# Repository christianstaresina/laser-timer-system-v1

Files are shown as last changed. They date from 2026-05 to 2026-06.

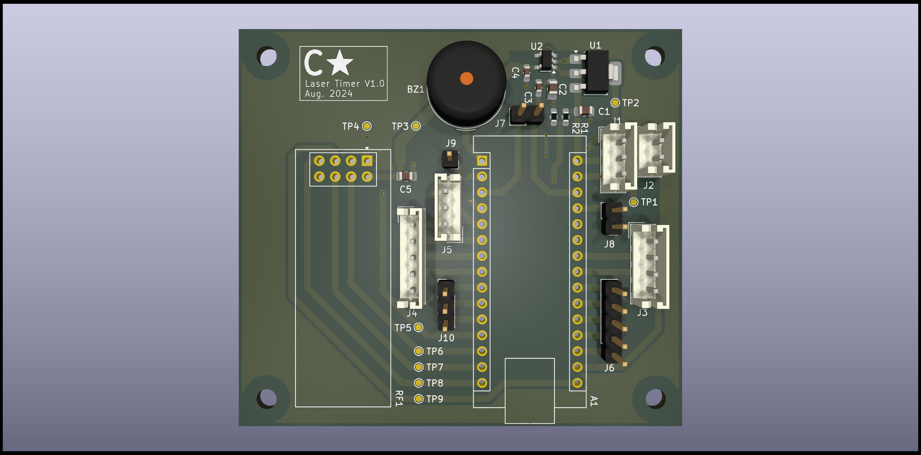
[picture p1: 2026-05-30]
docs/Laser_Timer_PCBA.jpg

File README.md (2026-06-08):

# Laser Timer System V1

A portable laser timer system consisting of a start gate and an end gate. When
the athlete crosses the start gate, the timer begins counting. When the athlete
crosses the end gate, the receiver stops the timer and shows the elapsed time on
its built-in LCD.

One common use is sprint timing: place the gates a measured distance apart,
start a run by crossing gate 1, then read the finish time and optional average
speed at gate 2.

## Repository layout

- `firmware/transmitter/laser_timer_v2_tx/` - Arduino sketch for the gate 1
  transmitter unit.
- `firmware/receiver/laser_timer_v2_rx/` - Arduino sketch for the gate 2
  receiver unit with LCD menu, stopwatch, speed settings, radio status, and
  buzzer settings.
- `firmware/common/radio_protocol_v2.h` - reference copy of the shared nRF24
  packet format. Each sketch also carries a local copy under `src/`; keep these
  protocol headers synchronized when changing radio commands or timing.
- `hardware/transmitter-or-receiver/` - KiCad source for the shared PCB.
- `production/transmitter-or-receiver/` - generated fabrication outputs,
  including Gerbers and BOM.

## Firmware v2 architecture

Firmware v2 uses two ATmega328-based units with nRF24L01+PA+LNA radios and
16x2 I2C LCDs:

1. The transmitter watches gate 1. When the gate 1 beam is broken, it sends a
   `CMD_GATE1_OPEN` burst to the receiver, shows "Timer counting", and waits for
   a finish message.
2. The receiver watches gate 2. When stopwatch mode is enabled and a gate 1
   open packet arrives, it starts timing. When the gate 2 beam is broken, it
   stops timing, displays the result, optionally displays speed, and sends
   `CMD_GATE2_CLOSED` back to the transmitter.
3. Both units use periodic or repeated packets for resilience: the transmitter
   sends heartbeat pings while idle and repeats gate-open packets while a run is
   active.

The shared radio protocol is defined by `radio_protocol_v2.h`:

- Packet shape: two packed bytes, `magic` (`0xA5`) and `cmd`.
- Commands: `CMD_GATE1_OPEN`, `CMD_GATE1_CLOSED`, `CMD_GATE2_CLOSED`, and
  `CMD_PING`.
- Radio settings: channel `108`, 250 Kbps data rate, 16-bit CRC, auto-ack
  enabled, and high PA level after startup settling.
- Pipe layout: address `"00002"` is transmitter-to-receiver, and `"00001"` is
  receiver-to-transmitter.

## Arduino setup

Open each sketch folder directly in the Arduino IDE:

- Transmitter: `firmware/transmitter/laser_timer_v2_tx`
- Receiver: `firmware/receiver/laser_timer_v2_rx`

Install the Arduino libraries used by the sketches:

- `RF24`
- `LiquidCrystal_I2C`
- Built-in Arduino libraries: `SPI`, `Wire`, and `EEPROM` (receiver settings)

The sketches are written for ATmega328-style boards. Source-verified pin usage:

| Function | Pin |
| --- | --- |
| Gate sensor input | `2` |
| Buzzer output | `1` |
| Encoder button | `3` |
| Encoder CLK | `4` |
| Encoder DAT | `5` |
| nRF24 CE | `9` |
| nRF24 CSN | `10` |
| SD card CS placeholder on receiver | `8` |
| Radio power enable | `A0` set `HIGH` at startup |
| LCD | I2C address `0x27`, 16 columns x 2 rows |

Both gate sensors are treated as active-high: `HIGH` means the laser beam is
broken.

## Operating workflow

1. Power the receiver and transmitter. Both show a pairing screen during radio
   startup. The transmitter blocks until it can send an acknowledged ping; the
   receiver shows "Link OK!" after the first valid packet.
2. Align both lasers. If a receiver beam is already broken while idle, the LCD
   shows "Align laser". The transmitter similarly shows "Gate 1 crossed" /
   "Align laser" if gate 1 starts open.
3. On the receiver, long-press the encoder button to open the menu, choose
   `Stopwatch`, then press the encoder. This enables the receiver to start a
   timed run from gate 1 packets.
4. Cross gate 1. The transmitter sends the start burst, beeps, and shows
   "Timer counting" / "Waiting gate 2". The receiver starts the stopwatch.
5. Cross gate 2. The receiver stops the timer, displays the finish time,
   optionally appends speed, sends the finish packet, and beeps if finish buzzer
   is enabled. The transmitter shows "Timer complete!" briefly before returning
   to its ready screen.

## Receiver menu and persisted settings

The receiver menu is controlled by the rotary encoder:

- Long press from the idle screen: open the main menu.
- Rotate: move through menu items.
- Short press: select the current item.
- Long press inside a menu: exit back to idle.

Main menu items:

- `Stopwatch` - enables timing. Gate 1 packets are ignored until this is
  selected.
- `Speed` - toggles speed display, selects preset distances (`40`, `10`, `5`,
  `2`, or `1` yard), edits a custom distance from `1` to `99` yards, and toggles
  display units between yards/MPH and meters/KPH. Distances are stored
  internally in yards; meter displays are converted from yards.
- `Radio` - shows link status or enters a re-pairing screen.
- `Buzzer` - toggles alignment and finish beeps independently.
- `Back` - returns to the idle display.

Receiver settings are stored in EEPROM at address `0` with magic byte `0x52`.
Defaults are speed enabled, 40-yard distance, 40-yard custom distance, align
buzzer enabled, finish buzzer enabled, and yard/MPH display units.

## Troubleshooting

- `Radio not found`: `radio.begin()` failed. Check nRF24 wiring, CE/CSN pins,
  SPI wiring, radio power, and the A0-controlled radio power rail.
- Pairing never completes: make sure both sketches use matching
  `radio_protocol_v2.h` values for channel, addresses, packet magic, and command
  IDs. The transmitter stays on the pairing screen until it receives an
  acknowledgement from the receiver.
- Receiver says `No TX signal`: the receiver has not seen a valid transmitter
  packet within the link timeout. Check transmitter power, radio range, antenna
  orientation, and matching protocol headers.
- Gate crossing does not start a run: enable `Stopwatch` from the receiver menu
  first. The receiver intentionally ignores gate 1 start packets while stopwatch
  mode is disabled.
- LCD says `Align laser`: the corresponding gate input is `HIGH`, which the
  firmware interprets as a broken beam. Re-align the laser/sensor pair or check
  sensor polarity.
- Speed looks wrong: verify the selected distance and units in the receiver
  `Speed` menu. KPH values are computed by converting the stored yard distance
  to meters.

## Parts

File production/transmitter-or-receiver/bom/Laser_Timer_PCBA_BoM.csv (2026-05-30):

# | Qty | DNP | Reference | Description | Value | Datasheet | Footprint
1 | 1 |  | A1 | Arduino Nano v3.x | Arduino_Nano_v3.x | http://www.mouser.com/pdfdocs/Gravitech_Arduino_Nano3_0.pdf | Module:Arduino_Nano
2 | 1 |  | BZ1 | Buzzer, polarized | Buzzer | ~ | Buzzer_Beeper:Buzzer_TDK_PS1240P02BT_D12.2mm_H6.5mm
3 | 2 |  | C1,C5 | Unpolarized capacitor, small symbol | 10uF | ~ | Capacitor_SMD:C_0805_2012Metric_Pad1.18x1.45mm_HandSolder
4 | 1 |  | C2 | Unpolarized capacitor, small symbol | 22uF | ~ | Capacitor_SMD:C_0805_2012Metric_Pad1.18x1.45mm_HandSolder
5 | 2 |  | C3,C4 | Unpolarized capacitor, small symbol | 1uF | ~ | Capacitor_SMD:C_0603_1608Metric_Pad1.08x0.95mm_HandSolder
6 | 4 |  | H1,H2,H3,H4 | Mounting Hole without connection | MountingHole | ~ | MountingHole:MountingHole_3.2mm_M3
7 | 1 |  | J1 | Generic connector, single row, 01x03, script generated | Pwr Btn and Battery | ~ | Connector_JST:JST_EH_B3B-EH-A_1x03_P2.50mm_Vertical
8 | 3 |  | J2,J7,J8 | Generic connector, single row, 01x02, script generated | Conn_01x02_Pin | ~ | Connector_JST:JST_EH_B2B-EH-A_1x02_P2.50mm_Vertical,Connector_PinHeader_2.54mm:PinHeader_1x02_P2.54mm_Vertical
9 | 1 |  | J3 | Generic connector, single row, 01x04, script generated | LCD | ~ | Connector_JST:JST_EH_B4B-EH-A_1x04_P2.50mm_Vertical
10 | 1 |  | J4 | Generic connector, single row, 01x05, script generated | Encoder | ~ | Connector_JST:JST_EH_B5B-EH-A_1x05_P2.50mm_Vertical
11 | 1 |  | J5 | Generic connector, single row, 01x03, script generated | Sensor | ~ | Connector_JST:JST_EH_B3B-EH-A_1x03_P2.50mm_Vertical
12 | 1 |  | J6 | Generic connector, single row, 01x05, script generated | Conn_01x05_Pin | ~ | Connector_PinHeader_2.54mm:PinHeader_1x05_P2.54mm_Vertical
13 | 1 |  | J9 | Generic connector, single row, 01x01, script generated | Conn_01x01_Pin | ~ | Connector_PinHeader_2.54mm:PinHeader_1x01_P2.54mm_Vertical
14 | 1 |  | J10 | Generic connector, single row, 01x03, script generated | Conn_01x03_Pin | ~ | Connector_PinHeader_2.54mm:PinHeader_1x03_P2.54mm_Vertical
15 | 2 |  | R1,R2 | Resistor, small US symbol | 510k | ~ | Resistor_SMD:R_0603_1608Metric_Pad0.98x0.95mm_HandSolder
16 | 1 |  | RF1 | Ultra low power 2.4GHz RF Transceiver, Carrier PCB | NRF24L01+PA+LNA | http://www.nordicsemi.com/eng/content/download/2730/34105/file/nRF24L01_Product_Specification_v2_0.pdf | RF_Module:nRF24L01+PA+LNA
17 | 9 |  | TP1,TP2,TP3,TP4,TP5,TP6,TP7,TP8,TP9 | test point | TestPoint | ~ | TestPoint:TestPoint_Pad_D1.0mm
18 | 1 |  | U1 | 1A 20V Fixed LDO Linear Regulator, 5.0V, SOT-89/SOT-223/TO-220/TO-252/TO-263 | AZ1117IH-5.0TRG1 | https://www.diodes.com/assets/Datasheets/AZ1117.pdf | Package_TO_SOT_SMD:SOT-223-3_TabPin2
19 | 1 |  | U2 | 500mA low dropout linear regulator, fixed 3.3V output, SOT-23-5 | MIC5504-3.3YM5-TR | http://ww1.microchip.com/downloads/en/DeviceDoc/MIC5219-500mA-Peak-Output-LDO-Regulator-DS20006021A.pdf | Package_TO_SOT_SMD:SOT-23-5

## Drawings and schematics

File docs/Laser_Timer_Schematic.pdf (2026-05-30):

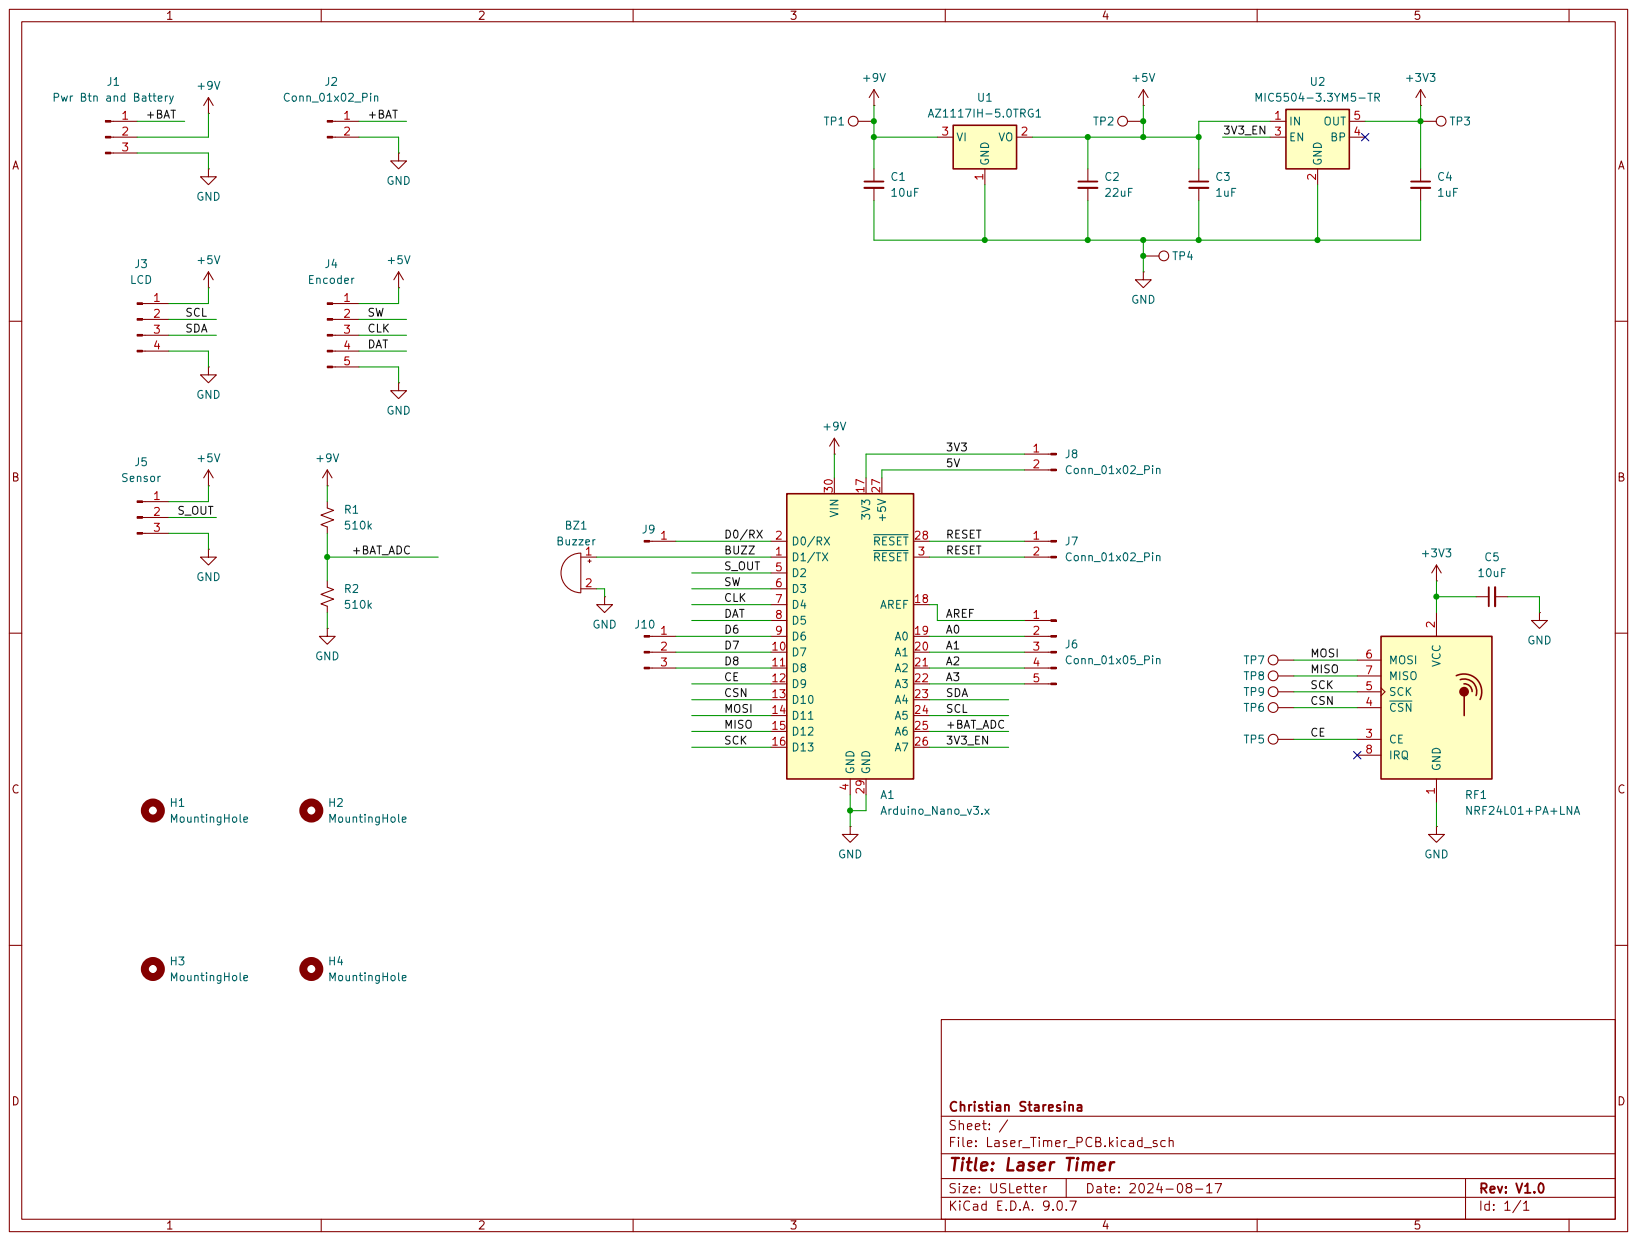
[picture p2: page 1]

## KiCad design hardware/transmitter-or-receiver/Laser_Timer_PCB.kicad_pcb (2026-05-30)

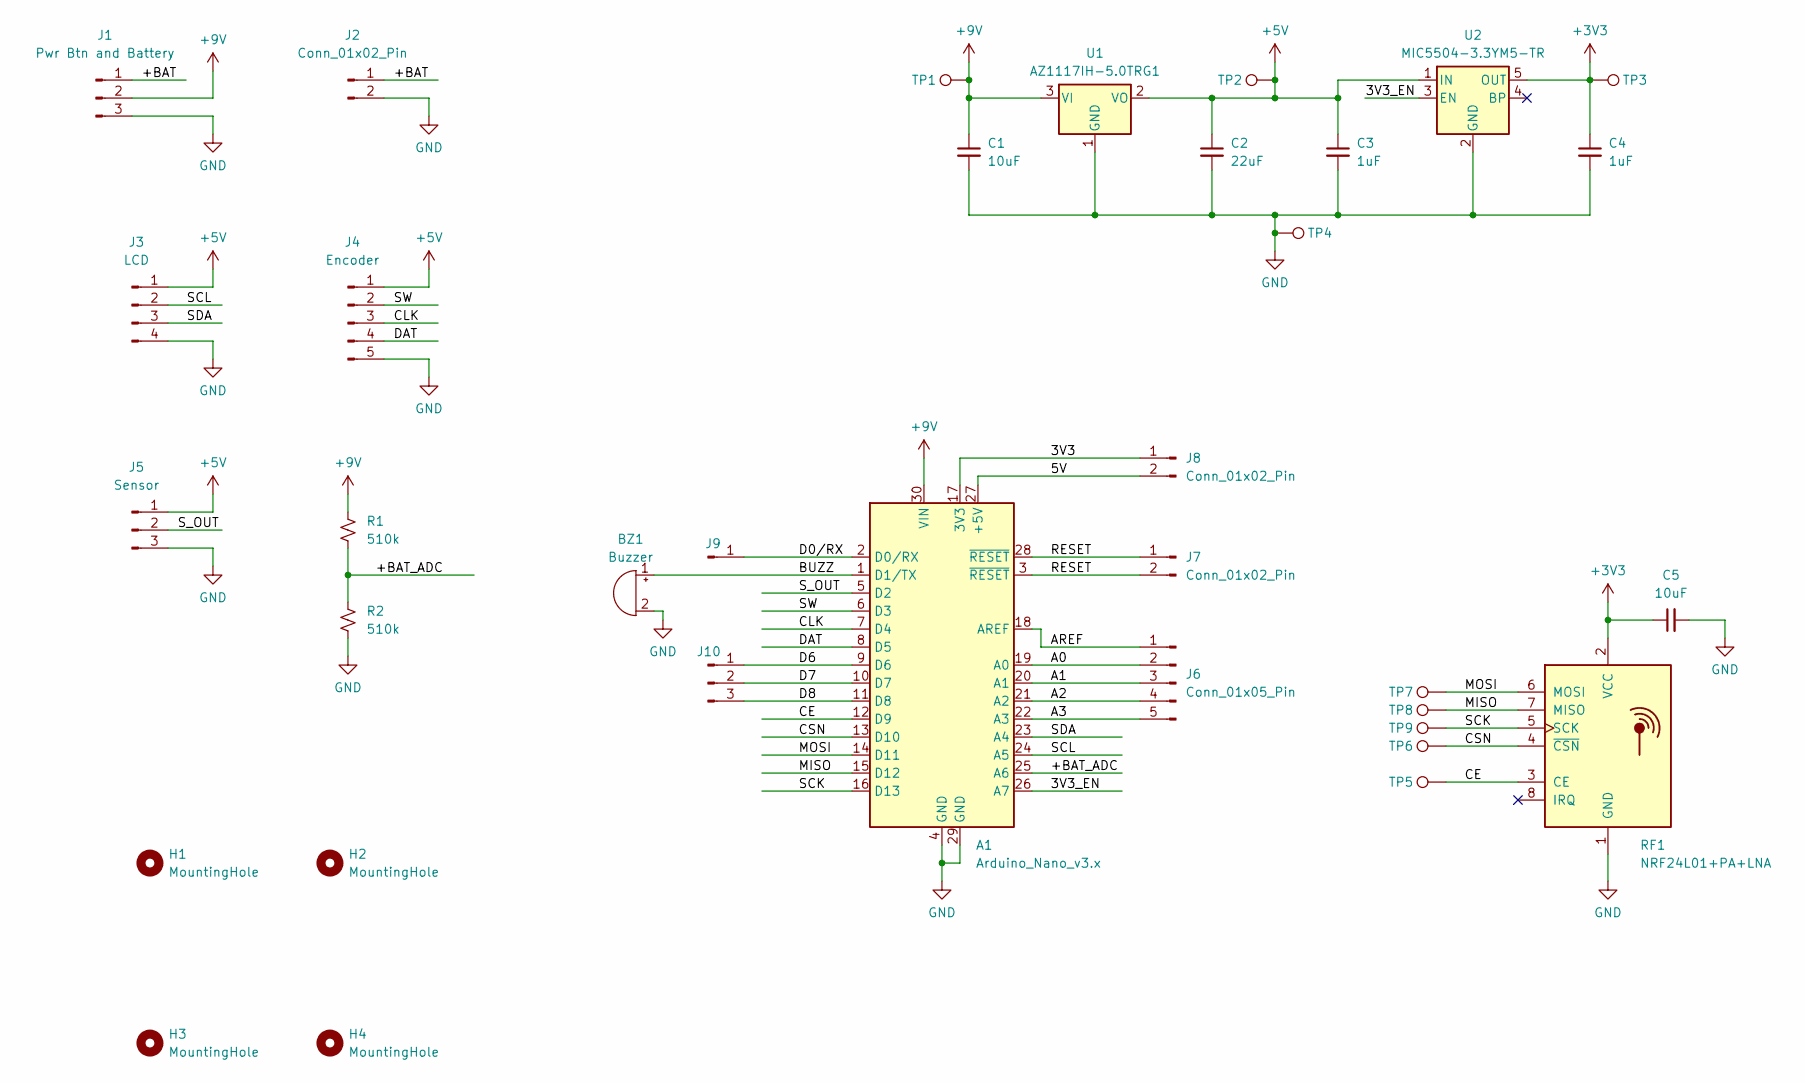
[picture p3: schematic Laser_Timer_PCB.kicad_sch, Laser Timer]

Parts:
A1: Arduino_Nano_v3.x; Arduino_Nano
BZ1: Buzzer; Buzzer_TDK_PS1240P02BT_D12.2mm_H6.5mm
C1, C5: 10uF; C_0805_2012Metric_Pad1.18x1.45mm_HandSolder
C2: 22uF; C_0805_2012Metric_Pad1.18x1.45mm_HandSolder
C3, C4: 1uF; C_0603_1608Metric_Pad1.08x0.95mm_HandSolder
H1, H2, H3, H4: MountingHole; MountingHole_3.2mm_M3
J1: Pwr Btn and Battery; JST_EH_B3B-EH-A_1x03_P2.50mm_Vertical
J2: Conn_01x02_Pin; JST_EH_B2B-EH-A_1x02_P2.50mm_Vertical
J3: LCD; JST_EH_B4B-EH-A_1x04_P2.50mm_Vertical
J4: Encoder; JST_EH_B5B-EH-A_1x05_P2.50mm_Vertical
J5: Sensor; JST_EH_B3B-EH-A_1x03_P2.50mm_Vertical
J6: Conn_01x05_Pin; PinHeader_1x05_P2.54mm_Vertical
J7, J8: Conn_01x02_Pin; PinHeader_1x02_P2.54mm_Vertical
J9: Conn_01x01_Pin; PinHeader_1x01_P2.54mm_Vertical
J10: Conn_01x03_Pin; PinHeader_1x03_P2.54mm_Vertical
R1, R2: 510k; R_0603_1608Metric_Pad0.98x0.95mm_HandSolder
RF1: NRF24L01+PA+LNA; nRF24L01+PA+LNA
TP1, TP2, TP3, TP4, TP5, TP6, TP7, TP8, TP9: TestPoint; TestPoint_Pad_D1.0mm
U1: AZ1117IH-5.0TRG1; SOT-223-3_TabPin2
U2: MIC5504-3.3YM5-TR; SOT-23-5

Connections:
+3V3: C4.1, C5.1, RF1.2 (VCC), TP3.1, U2.5 (OUT)
+5V: C2.1, C3.1, J3.1, J4.1, J5.1, TP2.1, U1.2 (VO), U2.1 (IN)
+9V: A1.30 (VIN), C1.1, J1.2, R1.1, TP1.1, U1.3 (VI)
/3V3: A1.17 (3V3), J8.1
/3V3_EN: A1.26 (A7), U2.3 (EN)
/5V: A1.27 (+5V), J8.2
/+BAT: J1.1, J2.1
/+BAT_ADC: A1.25 (A6), R1.2, R2.1
/A0: A1.19 (A0), J6.2
/A1: A1.20 (A1), J6.3
/A2: A1.21 (A2), J6.4
/A3: A1.22 (A3), J6.5
/AREF: A1.18 (AREF), J6.1
/BUZZ: A1.1 (D1/TX), BZ1.1 (+)
/CE: A1.12 (D9), RF1.3 (CE), TP5.1
/CLK: A1.7 (D4), J4.3
/CSN: A1.13 (D10), RF1.4 (~CSN), TP6.1
/D0/RX: A1.2 (D0/RX), J9.1
/D6: A1.9 (D6), J10.1
/D7: A1.10 (D7), J10.2
/D8: A1.11 (D8), J10.3
/DAT: A1.8 (D5), J4.4
/MISO: A1.15 (D12), RF1.7 (MISO), TP8.1
/MOSI: A1.14 (D11), RF1.6 (MOSI), TP7.1
/RESET: A1.3 (~RESET), A1.28 (~RESET), J7.1, J7.2
/SCK: A1.16 (D13), RF1.5 (SCK), TP9.1
/SCL: A1.24 (A5), J3.2
/SDA: A1.23 (A4), J3.3
/SW: A1.6 (D3), J4.2
/S_OUT: A1.5 (D2), J5.2
GND: A1.4 (GND), A1.29 (GND), BZ1.2 (-), C1.2, C2.2, C3.2, C4.2, C5.2, J1.3, J2.2, J3.4, J4.5, J5.3, R2.2, RF1.1 (GND), TP4.1, U1.1 (GND), U2.2 (GND)

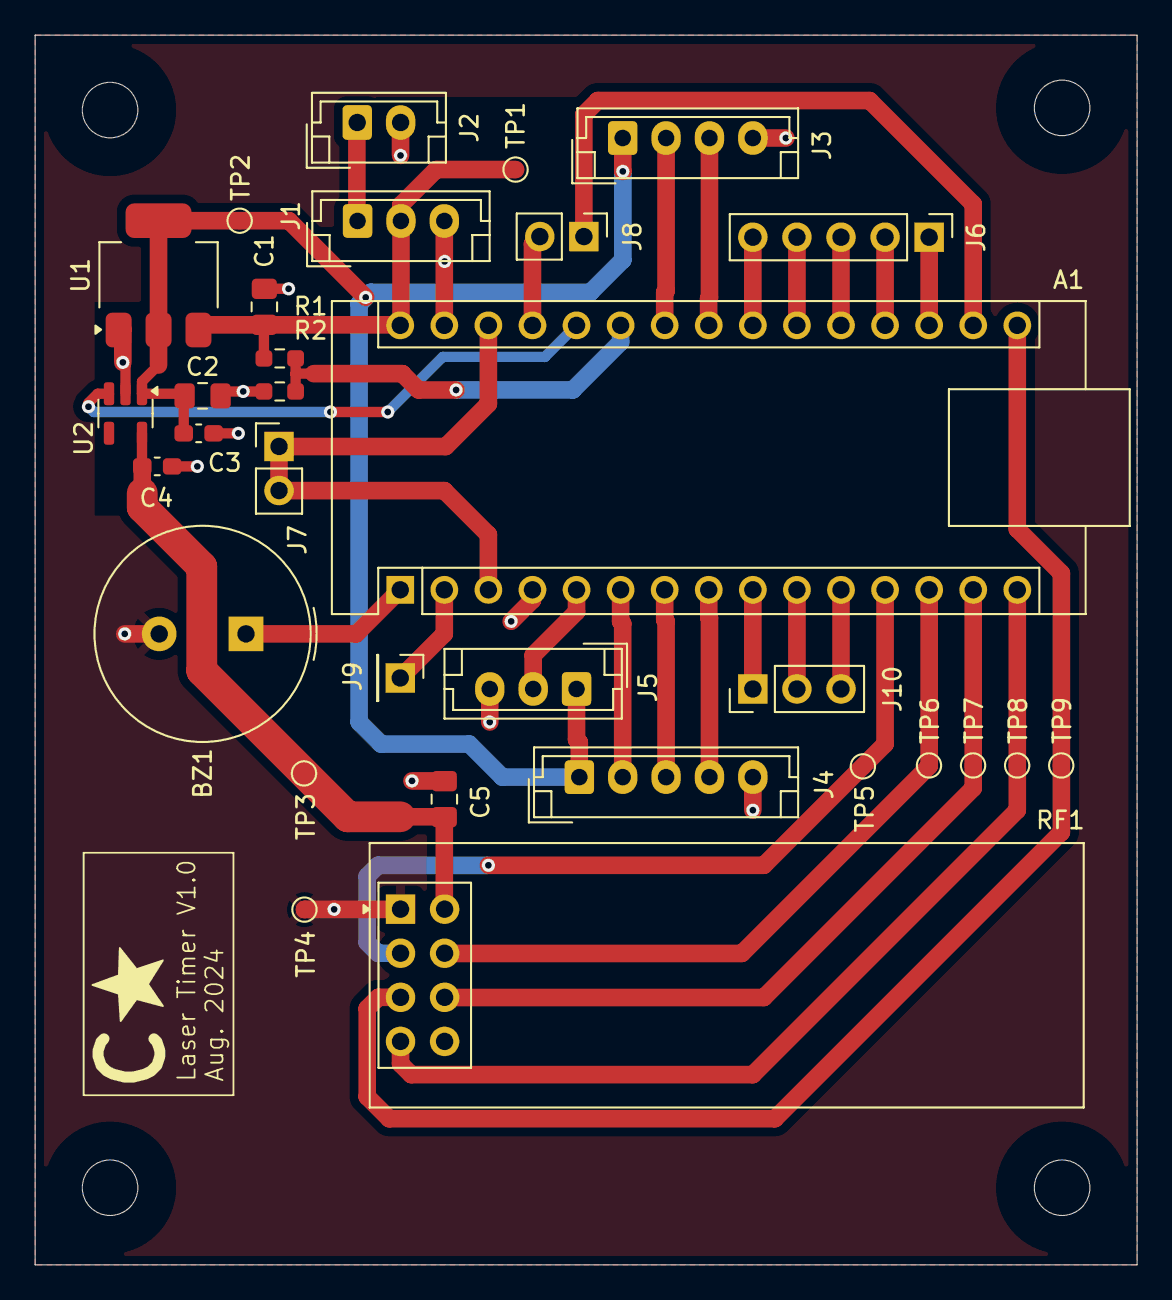
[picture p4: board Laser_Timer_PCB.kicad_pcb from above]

Board: 2 copper layers, 63.5 x 70.9 mm, 35 parts (0 on the bottom side), 31 nets.

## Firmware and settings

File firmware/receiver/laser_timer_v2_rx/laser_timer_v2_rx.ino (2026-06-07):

/**
 * laser_timer_v2_rx.ino
 * Laser Timer Firmware v2 — receiver (gate 2 / finish unit)
 *
 * Christian Staresina
 * 5/31/2026
 *
 * Hardware: ATmega328 + nRF24L01+PA+LNA, I2C LCD, gate 2 laser sensor, rotary encoder.
 * Open this sketch folder in Arduino IDE: firmware/receiver/laser_timer_v2_rx
 */

#include "src/functions_laser_timer_v2_rx.h"
#include "src/macros_laser_timer_v2_rx.h"
#include "src/settings_rx.h"
#include "src/menu_rx.h"
#include "src/encoder_rx.h"
#include "src/display_rx.h"
#include <SPI.h>
#include <RF24.h>
#include <Wire.h>
#include <LiquidCrystal_I2C.h>
extern LiquidCrystal_I2C lcd(0x27, 16, 2);

extern char timer_state;

extern const byte gate2_pin;
extern const byte radio_cs_pin;
extern const byte sd_cs_pin;

extern RF24 radio;
extern const byte addresses[][6];
extern bool radioReady;

void tickFirstPairing();

void setup() {
  pinMode(gate2_pin, INPUT);
  pinMode(buzzer_pin, OUTPUT);
  pinMode(radio_cs_pin, OUTPUT);
  pinMode(sd_cs_pin, OUTPUT);
  pinMode(A0, OUTPUT);
  digitalWrite(A0, HIGH);
  delay(RADIO_POWER_SETTLE_MS);

  encoderInit();
  loadSettings();
  menuInit();

  digitalWrite(radio_cs_pin, HIGH);
  digitalWrite(sd_cs_pin, HIGH);

  lcd.init();
  lcd.backlight();
  lcd.begin(16, 2);

  lcd.createChar(0, laserLeft);
  lcd.createChar(1, laserMid);
  lcd.createChar(2, laserRight);
  lcd.createChar(3, antenna);
  lcd.createChar(4, tripodLeft);
  lcd.createChar(5, tripodMid);
  lcd.createChar(6, tripodRight);
  lcd.createChar(7, backArrow);

  lcd.clear();
  lcd.setCursor(1, 0);
  lcd.print("LASER TIMER RX");
  lcd.setCursor(1, 1);
  lcd.print("Created by CS");
  delay(3000);

  lcd.clear();
  showPairingScreen();

  SPI.begin();
  radioReady = initRadio(radio);
  if (!radioReady) {
    lcd.setCursor(0, 0);
    lcd.print("Radio not found ");
    while (true) {
      delay(1000);
    }
  }

  radio.openReadingPipe(0, addresses[RADIO_TX_SEND_PIPE]);
  radio.startListening();
}

void loop() {
  static bool toastWasActive = false;

  PollRadio();
  tickFirstPairing();
  checkEncoderOpensMenu();

  if (!menuIsActive()) {
    Timer(timer_state);
    if (timer_state != ENABLED) {
      refreshLine1WhenIdle();
    }
  } else if (timer_state == ENABLED) {
    Sense_Gate2();
  }
  handleRxBuzzer();

  menuTick();

  bool toastNow = toastActive();
  toastTick();
  if (toastWasActive && !toastActive()) {
    if (menuIsActive()) {
      menuRefresh();
    } else {
      restoreIdleDisplay();
    }
  }
  toastWasActive = toastNow;
}

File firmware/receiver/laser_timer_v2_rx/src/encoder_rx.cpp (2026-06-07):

/**
 * encoder_rx.cpp
 * Laser Timer Firmware v2 — rotary encoder input
 */

#include "encoder_rx.h"

const int encoderButton = 3;
const byte encoderCLK = 4;
const byte encoderDAT = 5;

static int lastStateCLK = 0;
static unsigned long lastStepMs = 0;
static unsigned long buttonDownMs = 0;
static bool buttonWasDown = false;
static bool pressHandled = false;

void encoderInit() {
  pinMode(encoderCLK, INPUT);
  pinMode(encoderDAT, INPUT);
  pinMode(encoderButton, INPUT_PULLUP);
  lastStateCLK = digitalRead(encoderCLK);
}

EncoderEvent pollEncoder() {
  EncoderEvent event = EncNone;
  unsigned long now = millis();

  int currentStateCLK = digitalRead(encoderCLK);
  if (currentStateCLK != lastStateCLK && currentStateCLK == HIGH) {
    if (now - lastStepMs >= ENCODER_STEP_DEBOUNCE_MS) {
      lastStepMs = now;
      if (digitalRead(encoderDAT) != currentStateCLK) {
        event = EncCW;
      } else {
        event = EncCCW;
      }
    }
  }
  lastStateCLK = currentStateCLK;

  bool buttonDown = digitalRead(encoderButton) == LOW;
  if (buttonDown && !buttonWasDown) {
    buttonDownMs = now;
    pressHandled = false;
  }

  if (buttonDown && !pressHandled) {
    if (now - buttonDownMs >= ENCODER_LONG_PRESS_MS) {
      pressHandled = true;
      event = EncLongPress;
    }
  }

  if (!buttonDown && buttonWasDown && !pressHandled) {
    if (now - buttonDownMs >= ENCODER_BUTTON_DEBOUNCE_MS) {
      event = EncPress;
    }
    pressHandled = true;
  }

  buttonWasDown = buttonDown;
  return event;
}

void waitForEncoderRelease() {
  while (digitalRead(encoderButton) == LOW) {
    delay(1);
  }
  buttonWasDown = false;
  pressHandled = true;
}

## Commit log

2026-05-30 Add archived project files
    Transfers archived local copy of all the project files to GitHub for the first time. Most recent firmware changes were made in August 2024.
    [Laser_Timer_PCB.kicad_pcb, Laser_Timer_PCB.kicad_sch, Laser_Timer_PCBA_BoM.csv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]
2026-06-01 Add Laser Timer firmware v2 with reliable nRF24 link and improved UX.
    Replace v1 TX/RX sketches with laser_timer_v2_tx and laser_timer_v2_rx,
    shared radio_protocol_v2.h, pairing flow, ACK/retry radio, gate timing fixes,
    and transient LCD/buzzer behavior on both units.
    [functions_laser_timer_v2_rx.h, functions_laser_timer_v2_tx.h, laser_timer_v2_rx.ino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]
2026-06-07 Refactor RX menu into modular firmware with non-blocking pairing and improved LCD UX.
    Split menu, display, encoder, and settings into separate modules; allow menu access before first link; fix speed preview, units display, and status message clearing.
    [encoder_rx.cpp, functions_laser_timer_v2_rx.h, functions_laser_timer_v2_tx.h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]
